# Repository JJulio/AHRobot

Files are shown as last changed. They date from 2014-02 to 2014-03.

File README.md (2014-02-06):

Air Hockey Robot (AHRobot)
==========================

Detailed build intructions (Robot and Air Hockey table) [English]: https://docs.google.com/document/d/1SXIIW5MG1uT7O6P6tBWwzjiLe_gj4_Z2HHhHXPehwso/edit?usp=sharing

Intrucciones de montaje de la mesa y el robot[Español]: https://docs.google.com/document/d/1hYupLZCxkPqST7Fa1OjUVXbfluQ60mGxMKnmPQMFq5Q/edit?usp=sharing

Video:  https://www.youtube.com/watch?v=CjzSeOg8oTs

Air Hockey Robot build using standard 3D printer parts: electronics, motors, rods, belts,...

Project description (English): http://cienciaycacharreo.blogspot.com.es/2014/02/new-project-air-hockey-robot-3d-printer.html

Blog del proyecto (Spanish):  http://cienciaycacharreo.blogspot.com.es/2014/02/nuevo-proyecto-air-hockey-robot-3d.html

Jose Julio 2014

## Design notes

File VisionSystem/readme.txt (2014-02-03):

AHRobot vision system:

This vision system is designed for PS3 Eye camera and use OpenCV libraries

If you want to compile from sources you need to install and configure OpenCV libraries

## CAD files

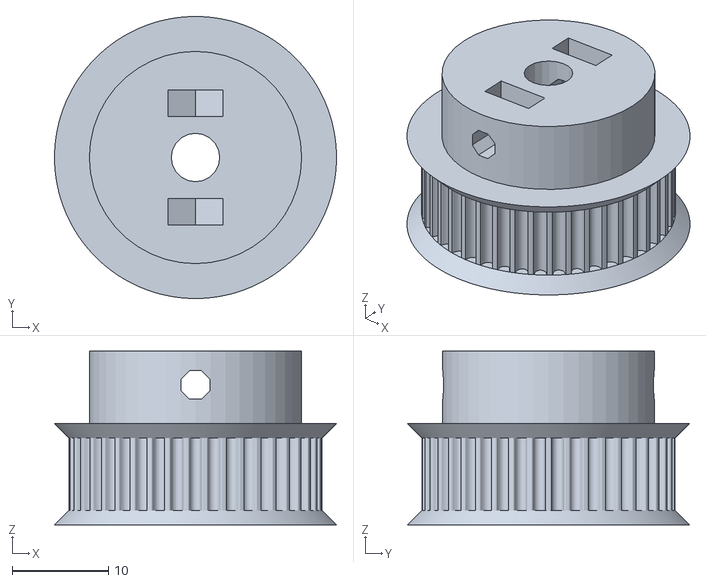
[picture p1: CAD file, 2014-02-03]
3DPrintable_parts/STL/AHR_Pulley_1.stl
29.2 x 29.2 x 18.0

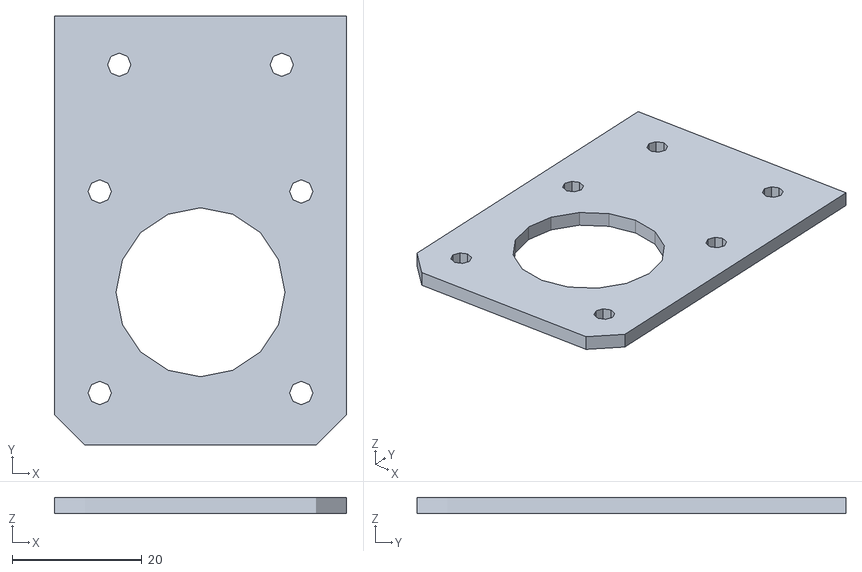
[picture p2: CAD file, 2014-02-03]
3DPrintable_parts/STL/AHR_x_motor_mount.stl
45.0 x 66.0 x 2.50

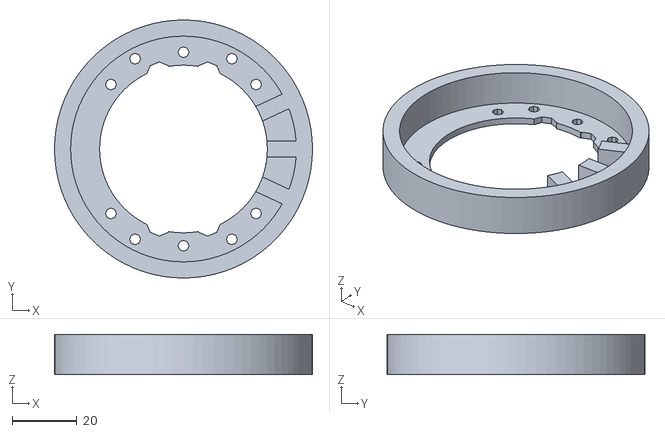
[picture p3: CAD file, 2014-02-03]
3DPrintable_parts/STL/AHR_x_carriage_pusher.stl
80.0 x 80.0 x 12.5

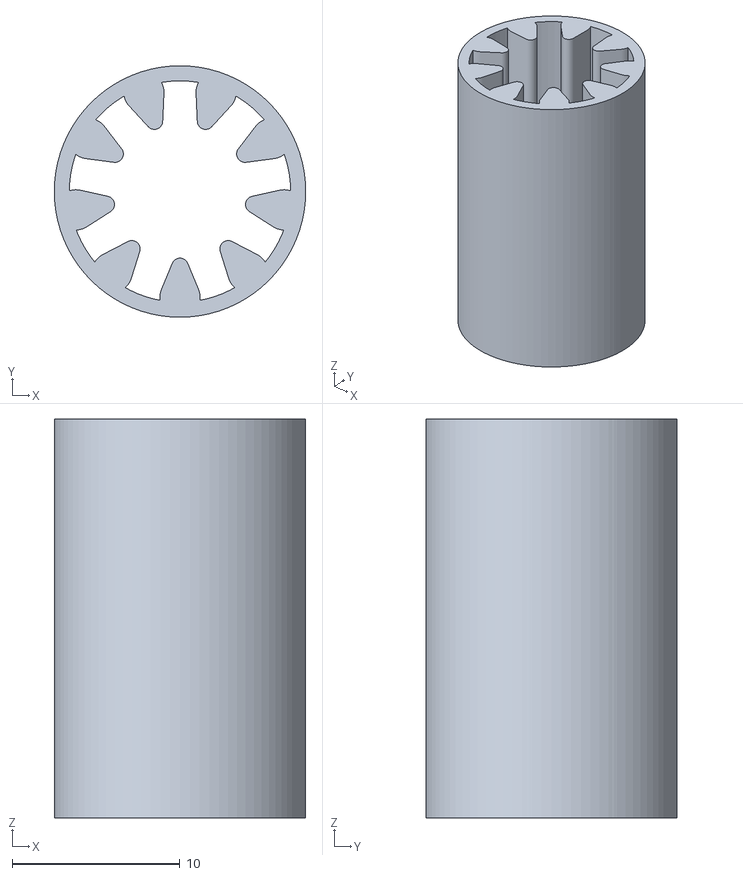
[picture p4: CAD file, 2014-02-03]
3DPrintable_parts/STL/PrintableBearing.stl
15.0 x 15.0 x 23.8

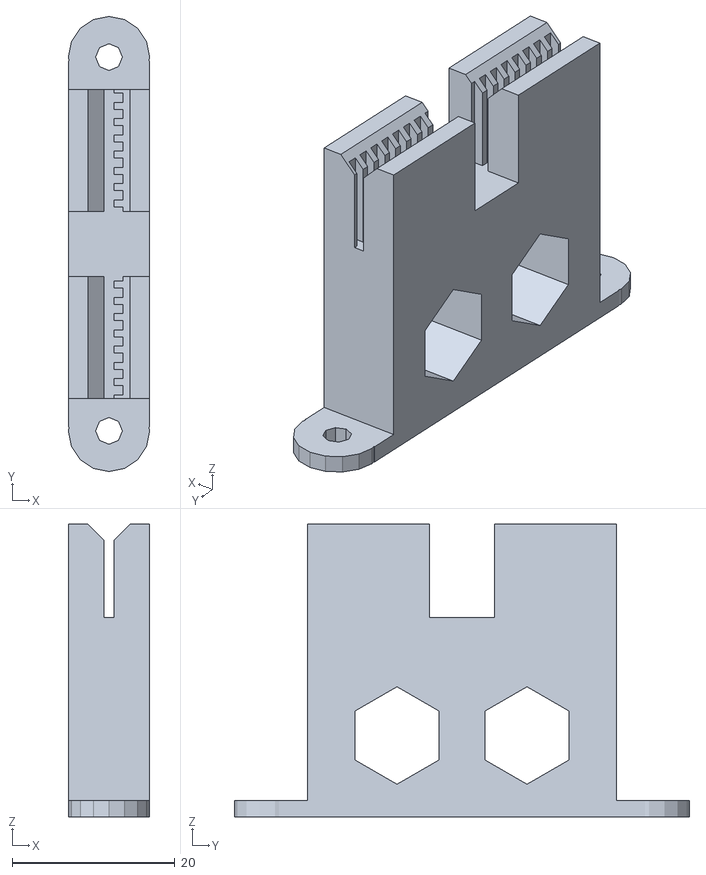
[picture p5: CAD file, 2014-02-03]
3DPrintable_parts/STL/AHR_x_carriage_belt.stl
10.0 x 56.0 x 36.0

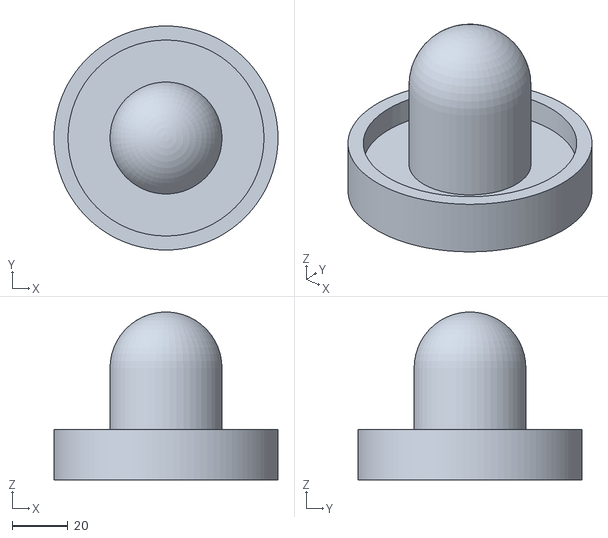
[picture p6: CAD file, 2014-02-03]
3DPrintable_parts/STL/pusher.stl
80.0 x 80.0 x 60.0

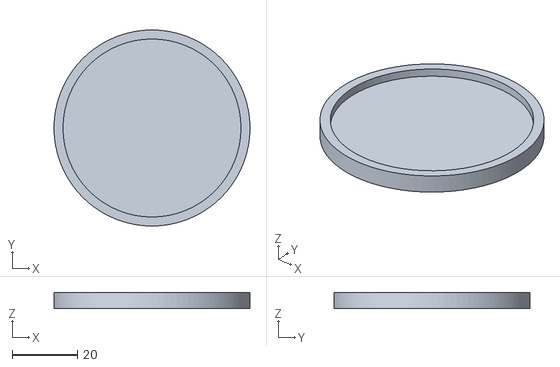
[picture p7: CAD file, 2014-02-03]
3DPrintable_parts/STL/puck_v2.stl
60.0 x 60.0 x 5.00

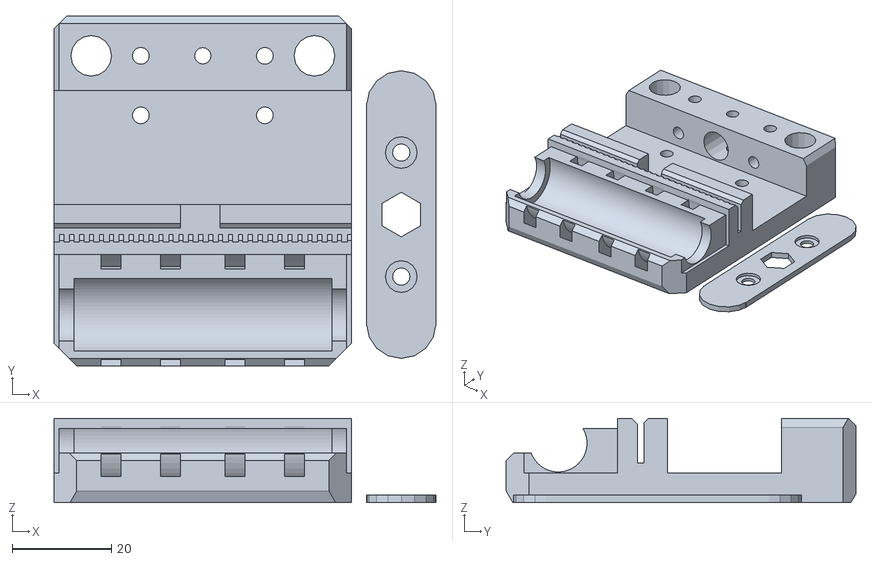
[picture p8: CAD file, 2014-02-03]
3DPrintable_parts/STL/AHR_y_carriage.stl
77.0 x 70.5 x 17.0

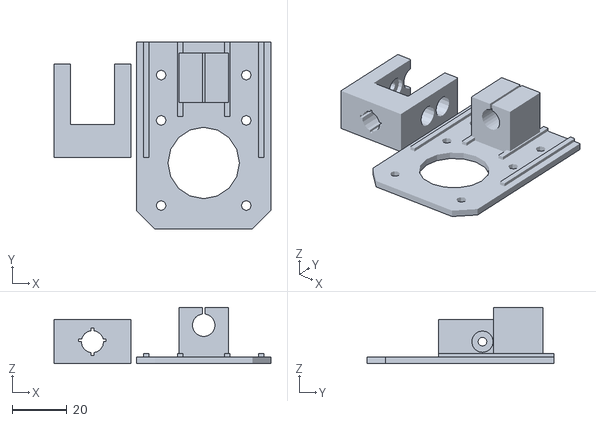
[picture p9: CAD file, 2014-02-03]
3DPrintable_parts/STL/AHR_y_axis_v2.stl
79.0 x 68.0 x 20.5

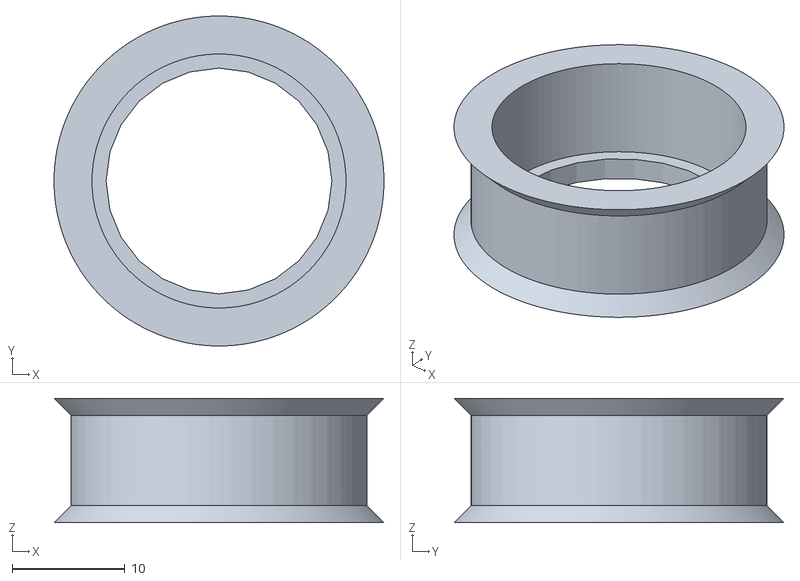
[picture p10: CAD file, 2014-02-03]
3DPrintable_parts/STL/AHR_Pulley_2.stl
29.2 x 29.2 x 11.0

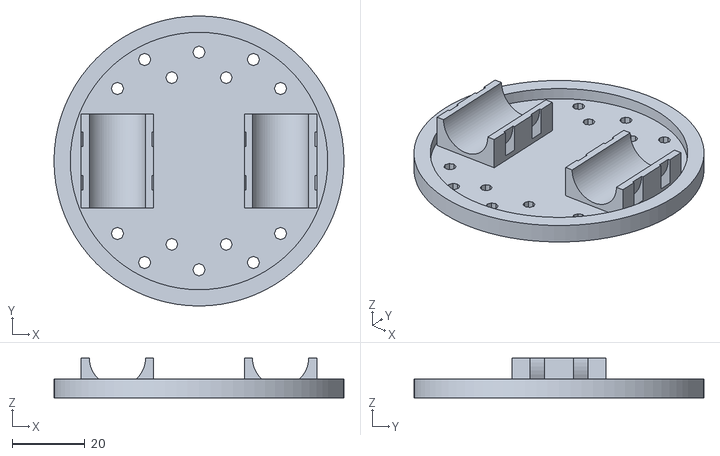
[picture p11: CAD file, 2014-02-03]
3DPrintable_parts/STL/AHR_x_carriage.stl
80.0 x 80.0 x 11.0

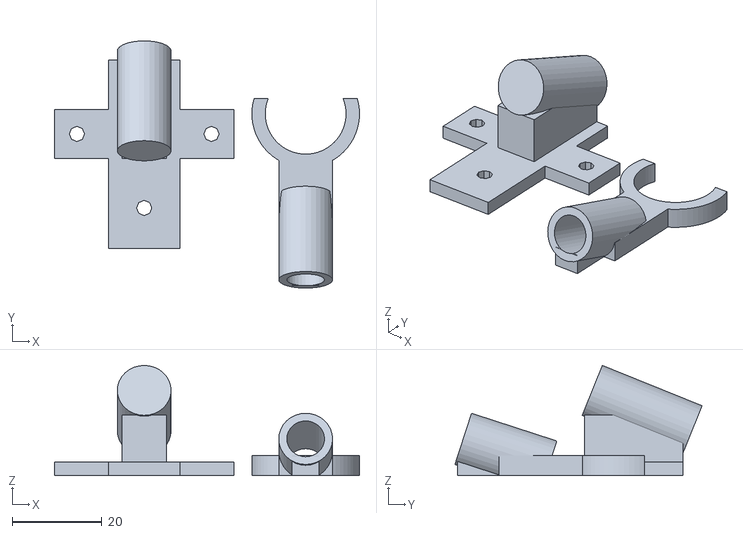
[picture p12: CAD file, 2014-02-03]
3DPrintable_parts/STL/AHR_PS3Camera_holder.stl
68.0 x 55.1 x 24.6

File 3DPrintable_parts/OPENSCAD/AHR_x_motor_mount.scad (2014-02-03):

// AIR HOCKEY ROBOT PROJECT (AHROBOT)
// 
// by Jose Julio

// X axis motor mount


motor_center_x = 22.5;
motor_center_y = -22.5;
base_height = 2.5;


module x_motor_mount_base()
{	
	translate([0,-46,0]) cube([45,46,base_height]); // Motor mount
	
	// mount part
	translate([0,0,0]) cube([motor_center_x*2,20,base_height]);

	// Reinforce
	//translate([2.5,-20,0]) cube([2,42,base_height*1.5]);
	//translate([16,-6,0]) cube([2,28,base_height*1.5]);
	//translate([32,-6,0]) cube([2,28,base_height*1.5]);
	//translate([45.5,-20,0]) cube([2,42,base_height*1.5]);

}

module x_motor_mount_holes()
{
	// Center motor hole
	translate([motor_center_x,motor_center_y,2]) cylinder(r=13,h=5,center=true,$fn=16);
	// Motor holes
	translate([motor_center_x-15.5,motor_center_y-15.5,2]) cylinder(r=1.8,h=5,center=true,$fn=8);
	translate([motor_center_x+15.5,motor_center_y-15.5,2]) cylinder(r=1.8,h=5,center=true,$fn=8);
	translate([motor_center_x-15.5,motor_center_y+15.5,2]) cylinder(r=1.8,h=5,center=true,$fn=8);
	translate([motor_center_x+15.5,motor_center_y+15.5,2]) cylinder(r=1.8,h=5,center=true,$fn=8);
 
	
   // Mount holes
	translate([motor_center_x-12.5,12.5,2]) cylinder(r=1.8,h=5,center=true,$fn=8);
	translate([motor_center_x+12.5,12.5,2]) cylinder(r=1.8,h=5,center=true,$fn=8);

	// motor mount cuts
	translate([motor_center_x*2+25,-motor_center_x*4+3,-1]) rotate([0,0,45]) cube([50,50,4]); // Motor mount
	translate([-25,-motor_center_x*4+3,-1]) rotate([0,0,45]) cube([50,50,4]); // Motor mount

}





translate([0,0,0]) rotate ([0,0,0]) difference()
{
x_motor_mount_base();
x_motor_mount_holes();
}

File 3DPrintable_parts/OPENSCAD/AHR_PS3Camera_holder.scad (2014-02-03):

// AIR HOCKEY ROBOT PROJECT (AHROBOT)
// 
// by Jose Julio

// PS3 Camera holder (needs a 8mm carbon tube)

module rod_base(angle=20,height=20)
{
	rotate([angle,0,0]) cylinder(r=6,h=height,$fn=32);
}

module rod_holes(angle=20,height=22)
{
	rotate([angle,0,0]) cylinder(r=4.2,h=height,$fn=32);
}

module PS3Cam_base()
{
	cylinder(r=12,h=4.5,$fn=64);
	translate([-6,-29,0]) cube([12,20,4.5]);
	// Support to print the rod holder
	translate([-3,-38.3,0]) cube([6,30,4.5]);
	// Rod holder
	translate([0,-18,2]) rod_base(72);
}

module PS3Cam_holes()
{
	translate([-15,3.4,-1]) cube([30,20,10]);
	translate([0,0,-1]) cylinder(r=9,h=6,$fn=64);
	// Rod holder
	translate([0,-18,2]) rod_holes(72);
	// Cut elements lower than 0
	translate([0,0,-5]) cube([200,200,10],center=true);
}

module base()
{
	translate([-20,0,0]) cube([40,11,3]);
	translate([-8,-20,0]) cube([16,42,3]);
	//translate([-8,-33,0]) cube([16,49,3]);
	//translate([-20,-11-22,0]) cube([40,11,3]);
	// Rod reinforcement
	translate([-5,0,2.5]) cube([10,22,11]);
	
	// Rod holder
	translate([0,24,10]) rod_base(68,24);
}

module holes()
{
	translate([-15,5.5,0]) cylinder(r=1.7,h=10,$fn=8,center=true);
	translate([15,5.5,0]) cylinder(r=1.7,h=10,$fn=8,center=true);
	translate([0,-11,0]) cylinder(r=1.7,h=10,$fn=8,center=true);

	//translate([-15,-27.5,0]) cylinder(r=1.7,h=10,$fn=8,center=true);
	//translate([15,-27.5,0]) cylinder(r=1.7,h=10,$fn=8,center=true);
	
// rod holder
	translate([0,24,10]) rod_holes(68,22);

	// Cut elements lower than 0
	translate([0,0,-5]) cube([200,200,10],center=true);
}


difference()
{
 base();
 holes();
}


translate([36,10,0]) difference()
{
 PS3Cam_base();
 PS3Cam_holes();
}

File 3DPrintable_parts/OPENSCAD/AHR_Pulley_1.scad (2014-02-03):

// AIR HOCKEY ROBOT PROJECT (AHROBOT)
// 
// 42 teeth GT2 pulley based on:

// Parametric Pulley with multiple belt profiles
// by droftarts January 2012

// Based on pulleys by:
// http://www.thingiverse.com/thing:11256 by me!
// https://github.com/prusajr/PrusaMendel by Josef Prusa
// http://www.thingiverse.com/thing:3104 by GilesBathgate
// http://www.thingiverse.com/thing:2079 by nophead

// dxf tooth data from http://oem.cadregister.com/asp/PPOW_Entry.asp?company=915217&elementID=07807803/METRIC/URETH/WV0025/F
// pulley diameter checked and modelled from data at http://www.sdp-si.com/D265/HTML/D265T016.html

/**
 * @name Pulley
 * @category Printed
 * @using 1 x m3 nut, normal or nyloc
 * @using 1 x m3x10 set screw or 1 x m3x8 grub screw
 */

// tuneable constants

teeth = 42;			// Number of teeth
profile = 12;		// GT2_2mm 1=MXL 2=40DP 3=XL 4=H 5=T2.5 6=T5 7=T10 8=AT5 9=HTD_3mm 10=HTD_5mm 11=HTD_8mm 12=GT2_2mm 13=GT2_3mm 14=GT2_5mm

motor_shaft = 5.03;	// NEMA17 motor shaft exact diameter = 5
m3_dia = 3.2;		// 3mm hole diameter
m3_nut_hex = 1;		// 1 for hex, 0 for square nut
m3_nut_flats = 5.74;	// normal M3 hex nut exact width = 5.5
m3_nut_depth = 2.74;	// normal M3 hex nut exact depth = 2.4, nyloc = 4

retainer = 1;		// Belt retainer above teeth, 0 = No, 1 = Yes
retainer_ht = 1.5;	// height of retainer flange over pulley, standard = 1.5
idler = 1;			// Belt retainer below teeth, 0 = No, 1 = Yes
idler_ht = 1.5;		// height of idler flange over pulley, standard = 1.5

pulley_t_ht = 7.5;	// length of toothed part of pulley, standard = 12
pulley_b_ht = 9;		// pulley base height, standard = 8. Set to same as idler_ht if you want an idler but no pulley.
pulley_b_dia = 22;	// pulley base diameter, standard = 20
no_of_nuts = 2;		// number of captive nuts required, standard = 1
nut_angle = 180;		// angle between nuts, standard = 90
nut_shaft_distance = 1.75;	// distance between inner face of nut and shaft, can be negative.


//	********************************
//	** Scaling tooth for good fit **
//	********************************
/*	To improve fit of belt to pulley, set the following constant. Decrease or increase by 0.1mm at a time. We are modelling the *BELT* tooth here, not the tooth on the pulley. Increasing the number will *decrease* the pulley tooth size. Increasing the tooth width will also scale proportionately the tooth depth, to maintain the shape of the tooth, and increase how far into the pulley the tooth is indented. Can be negative */

additional_tooth_width = 0.1; //mm

//	If you need more tooth depth than this provides, adjust the following constant. However, this will cause the shape of the tooth to change.

additional_tooth_depth = 0.2; //mm

// calculated constants

nut_elevation = pulley_b_ht/2-1;
m3_nut_points = 2*((m3_nut_flats/2)/cos(30)); // This is needed for the nut trap

// The following set the pulley diameter for a given number of teeth

MXL_pulley_dia = tooth_spacing (2.032,0.254);
40DP_pulley_dia = tooth_spacing (2.07264,0.1778);
XL_pulley_dia = tooth_spacing (5.08,0.254);
H_pulley_dia = tooth_spacing (9.525,0.381);
T2_5_pulley_dia = tooth_spaceing_curvefit (0.7467,0.796,1.026);
T5_pulley_dia = tooth_spaceing_curvefit (0.6523,1.591,1.064);
T10_pulley_dia = tooth_spacing (10,0.93);
AT5_pulley_dia = tooth_spaceing_curvefit (0.6523,1.591,1.064);
HTD_3mm_pulley_dia = tooth_spacing (3,0.381);
HTD_5mm_pulley_dia = tooth_spacing (5,0.5715);
HTD_8mm_pulley_dia = tooth_spacing (8,0.6858);
GT2_2mm_pulley_dia = tooth_spacing (2,0.254);
GT2_3mm_pulley_dia = tooth_spacing (3,0.381);
GT2_5mm_pulley_dia = tooth_spacing (5,0.5715);

// The following calls the pulley creation part, and passes the pulley diameter and tooth width to that module

if ( profile == 1 ) { pulley ( "MXL" , MXL_pulley_dia , 0.508 , 1.321 ); }
if ( profile == 2 ) { pulley ( "40 D.P." , 40DP_pulley_dia , 0.457 , 1.226 ); }
if ( profile == 3 ) { pulley ( "XL" , XL_pulley_dia , 1.27, 3.051 ); }
if ( profile == 4 ) { pulley ( "H" , H_pulley_dia ,1.905 , 5.359 ); }
if ( profile == 5 ) { pulley ( "T2.5" , T2_5_pulley_dia , 0.7 , 1.678 ); }
if ( profile == 6 ) { pulley ( "T5" , T5_pulley_dia , 1.19 , 3.264 ); }
if ( profile == 7 ) { pulley ( "T10" , T10_pulley_dia , 2.5 , 6.13 ); }
if ( profile == 8 ) { pulley ( "AT5" , AT5_pulley_dia , 1.19 , 4.268 ); }
if ( profile == 9 ) { pulley ( "HTD 3mm" , HTD_3mm_pulley_dia , 1.289 , 2.27 ); }
if ( profile == 10 ) { pulley ( "HTD 5mm" , HTD_5mm_pulley_dia , 2.199 , 3.781 ); }
if ( profile == 11 ) { pulley ( "HTD 8mm" , HTD_8mm_pulley_dia , 3.607 , 6.603 ); }
if ( profile == 12 ) { pulley ( "GT2 2mm" , GT2_2mm_pulley_dia , 0.764 , 1.494 ); }
if ( profile == 13 ) { pulley ( "GT2 3mm" , GT2_3mm_pulley_dia , 1.169 , 2.31 ); }
if ( profile == 14 ) { pulley ( "GT2 5mm" , GT2_5mm_pulley_dia , 1.969 , 3.952 ); }

// Functions

function tooth_spaceing_curvefit (b,c,d)
	= ((c * pow(teeth,d)) / (b + pow(teeth,d))) * teeth ;

function tooth_spacing(tooth_pitch,pitch_line_offset)
	= (2*((teeth*tooth_pitch)/(3.14159265*2)-pitch_line_offset)) ;

// Main Module

module pulley( belt_type , pulley_OD , tooth_depth , tooth_width )
	{
	echo (str("Belt type = ",belt_type,"; Number of teeth = ",teeth,"; Pulley Outside Diameter = ",pulley_OD,"mm "));
	tooth_distance_from_centre = sqrt( pow(pulley_OD/2,2) - pow((tooth_width+additional_tooth_width)/2,2));
	tooth_width_scale = (tooth_width + additional_tooth_width ) / tooth_width;
	tooth_depth_scale = ((tooth_depth + additional_tooth_depth ) / tooth_depth) ;


//	************************************************************************
//	*** uncomment the following line if pulley is wider than puller base ***
//	************************************************************************

	translate ([0,0, pulley_b_ht + pulley_t_ht + retainer_ht ]) rotate ([0,180,0])

	difference()
	 {	 
		union()
		{
			//base
	
			if ( pulley_b_ht < 2 ) { echo ("CAN'T DRAW PULLEY BASE, HEIGHT LESS THAN 2!!!"); } else {
				rotate_extrude($fn=pulley_b_dia*2)
				{
						square([pulley_b_dia/2-1,pulley_b_ht]);
						square([pulley_b_dia/2,pulley_b_ht-1]);
						translate([pulley_b_dia/2-1,pulley_b_ht-1]) circle(1);
				}
			}
	
		difference()
			{
			//shaft - diameter is outside diameter of pulley
			
			translate([0,0,pulley_b_ht]) 
			rotate ([0,0,360/(teeth*4)]) 
			cylinder(r=pulley_OD/2,h=pulley_t_ht, $fn=teeth*4);
	
			//teeth - cut out of shaft
		
			for(i=[1:teeth]) 
			rotate([0,0,i*(360/teeth)])
			translate([0,-tooth_distance_from_centre,pulley_b_ht -1]) 
			scale ([ tooth_width_scale , tooth_depth_scale , 1 ]) 
			{
			if ( profile == 1 ) { MXL();}
			if ( profile == 2 ) { 40DP();}
			if ( profile == 3 ) { XL();}
			if ( profile == 4 ) { H();}
			if ( profile == 5 ) { T2_5();}
			if ( profile == 6 ) { T5();}
			if ( profile == 7 ) { T10();}
			if ( profile == 8 ) { AT5();}
			if ( profile == 9 ) { HTD_3mm();}
			if ( profile == 10 ) { HTD_5mm();}
			if ( profile == 11 ) { HTD_8mm();}
			if ( profile == 12 ) { GT2_2mm();}
			if ( profile == 13 ) { GT2_3mm();}
			if ( profile == 14 ) { GT2_5mm();}
			}

			}
			
		//belt retainer / idler
		if ( retainer > 0 ) {translate ([0,0, pulley_b_ht + pulley_t_ht ]) 
		rotate_extrude($fn=teeth*4)  
		polygon([[0,0],[pulley_OD/2,0],[pulley_OD/2 + retainer_ht , retainer_ht],[0 , retainer_ht],[0,0]]);}
		
		if ( idler > 0 ) {translate ([0,0, pulley_b_ht - idler_ht ]) 
		rotate_extrude($fn=teeth*4)  
		polygon([[0,0],[pulley_OD/2 + idler_ht,0],[pulley_OD/2 , idler_ht],[0 , idler_ht],[0,0]]);}
	
		}
	   
		//hole for motor shaft
		translate([0,0,-1])cylinder(r=motor_shaft/2,h=pulley_b_ht + pulley_t_ht + retainer_ht + 2,$fn=motor_shaft*4);
				
		//captive nut and grub screw holes
	
		if ( pulley_b_ht < m3_nut_flats ) { echo ("CAN'T DRAW CAPTIVE NUTS, HEIGHT LESS THAN NUT DIAMETER!!!"); } else {
		if ( (pulley_b_dia - motor_shaft)/2 < m3_nut_depth + 3 ) { echo ("CAN'T DRAW CAPTIVE NUTS, DIAMETER TOO SMALL FOR NUT DEPTH!!!"); } else {
	
			for(j=[1:no_of_nuts]) rotate([0,0,j*nut_angle])
			translate([0,0,nut_elevation])rotate([90,0,0])
	
			union()
			{
				//entrance
				translate([0,-pulley_b_ht/4-0.5,motor_shaft/2+m3_nut_depth/2+nut_shaft_distance]) cube([m3_nut_flats,pulley_b_ht/2+1,m3_nut_depth],center=true);
	
				//nut
				if ( m3_nut_hex > 0 )
					{
						// hex nut
						translate([0,0.25,motor_shaft/2+m3_nut_depth/2+nut_shaft_distance]) rotate([0,0,30]) cylinder(r=m3_nut_points/2,h=m3_nut_depth,center=true,$fn=6);
					} else {
						// square nut
						translate([0,0.25,motor_shaft/2+m3_nut_depth/2+nut_shaft_distance]) cube([m3_nut_flats,m3_nut_flats,m3_nut_depth],center=true);
					}
	
				//grub screw hole
				rotate([0,0,22.5])cylinder(r=m3_dia/2,h=pulley_b_dia/2+1,$fn=8);
			}
		}}
	 }
	   
	}


// Tooth profile modules
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

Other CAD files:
3DPrintable_parts/OPENSCAD/AHR_Pulley_2.scad
3DPrintable_parts/OPENSCAD/AHR_x_carriage.scad
3DPrintable_parts/OPENSCAD/AHR_x_carriage_belt.scad
3DPrintable_parts/OPENSCAD/AHR_x_carriage_pusher.scad
3DPrintable_parts/OPENSCAD/AHR_y_axis_v2.scad
3DPrintable_parts/OPENSCAD/AHR_y_carriage.scad
3DPrintable_parts/OPENSCAD/PrintableBearing.scad
3DPrintable_parts/OPENSCAD/puck_v2.scad
3DPrintable_parts/OPENSCAD/pusher.scad

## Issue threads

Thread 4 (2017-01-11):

Question

shinichikudou09, 2017-01-11:
Sir JJulio can i ask a question? about the main function. the argument

if (argc < 2)
	{
		printf("USAGE: AHR.exe COMPORT PUCK_HMIN PUCK_HMAX PUCK_SMIN PUCK_SMAX PUCK_VMIN PUCK_VMAX ROBOT_HMIN ROBOT_HMAX ROBOT_SMIN ROBOT_SMAX ROBOT_VMIN ROBOT_VMAX FPS\n");
		printf("Example with default paremeters: AHR.exe COM18\n");
		// H : 70-94 S: 60-150 V: 10-145   GREEN EVA FOAM (PUCK)
		// H : 5-20  S: 110-200 V: 90-200  ORANGE EVA FOAM (ROBOT)
		printf("Example full parameters: AHR.exe COM4 70 94 60 150 10 145 5 20 110 200 90 200 60\n");
		return -1;
	}

always get executed do you know why? is it about the wchar_t* things? i am using Microsoft Visual c++ 2010 Express.

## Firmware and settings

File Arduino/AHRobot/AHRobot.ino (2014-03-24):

// AHR: AIR HOCKEY ROBOT PROJECT
// Author: Jose Julio (@jjdrones)
// Hardware: Arduino MEGA + Ramps 1.4
// Date: 18/11/2013
// Last updated: 24/03/2014
// Version: 1.05
// Project page : 
//    Spanish: http://cienciaycacharreo.blogspot.com.es/2014/02/nuevo-proyecto-air-hockey-robot-3d.html 
//    English: http://cienciaycacharreo.blogspot.com.es/2014/02/new-project-air-hockey-robot-3d-printer.html
// GIT repository: https://github.com/JJulio/AHRobot
// License: Open Software GPL License

// ROBOT and USER configuration parameters
#include "Configuration.h"
#include "Definitions.h"   // Variable definitions

void setup() 
{ 
  // STEPPER MOTOR PINS (SAME AS RAMPS 1.4)
  // X MOTOR
  //     X-STEP: A0    (PF0)
  //     X-DIR:  A1    (PF1)
  //     X-ENABLE: D38 (PD7)
  // Y MOTOR (Y-LEFT)
  //     Y-STEP: A6    (PF6)
  //     Y-DIR:  A7    (PF7)
  //     Y-ENABLE: A2  (PF2)
  // Z MOTOR (Y-RIGHT)
  //     Z-STEP: D46   (PL3)
  //     Z-DIR:  D48   (PL1)
  //     Z-ENABLE: A8  (PK0)

  // STEPPER PINS 
  // X_AXIS
  pinMode(38,OUTPUT);  // ENABLE MOTOR
  pinMode(A0,OUTPUT);  // STEP MOTOR
  pinMode(A1,OUTPUT);  // DIR MOTOR
  // Y_AXIS (Y-LEFT)
  pinMode(A2,OUTPUT);  // ENABLE MOTOR
  pinMode(A6,OUTPUT);  // STEP MOTOR
  pinMode(A7,OUTPUT);  // DIR MOTOR
  // Z_AXIS (Y-RIGHT)
  pinMode(A8,OUTPUT);  // ENABLE MOTOR
  pinMode(46,OUTPUT);  // STEP MOTOR
  pinMode(48,OUTPUT);  // DIR MOTOR 

  pinMode(A3,OUTPUT);  // DEBUG PIN FOR OSCILLOSCOPE TIME MEASURES

  pinMode(19,INPUT);  // RX1 Serial Port 1
  pinMode(18,OUTPUT); // TX1

  //FANS and LEDS
  pinMode(8,OUTPUT);
  pinMode(9,OUTPUT);
  pinMode(10,OUTPUT);
  pinMode(13,OUTPUT);

  // Disable Motors
  digitalWrite(38,HIGH);
  digitalWrite(A2,HIGH);
  digitalWrite(A8,HIGH);

  Serial.begin(115200);
  Serial.println("AHR Robot version 1.05");
  delay(500);
  Serial.println("Initializing robot...");
  delay(2000);

  cameraProcessInit();  // Camera variable initializations
  
  // Robot positions initialization
  defense_position = ROBOT_DEFENSE_POSITION;   // Robot y axis defense position
  attack_position = ROBOT_DEFENSE_ATTACK_POSITION;   // Robot y axis position for defense+attack

  //LED blink
  for (uint8_t k=0;k<4;k++)
  {
    digitalWrite(13,HIGH);
    delay(300);
    digitalWrite(13,LOW);
    delay(300);
  } 

  // We use TIMER 1 for stepper motor X AXIS and Timer 3 for Y AXIS
  // STEPPER MOTORS INITIALIZATION
  // TIMER1 CTC MODE
  TCCR1B &= ~(1<<WGM13);
  TCCR1B |=  (1<<WGM12);
  TCCR1A &= ~(1<<WGM11); 
  TCCR1A &= ~(1<<WGM10);

  // output mode = 00 (disconnected)
  TCCR1A &= ~(3<<COM1A0); 
  TCCR1A &= ~(3<<COM1B0); 

  // Set the timer pre-scaler
  // Generally we use a divider of 8, resulting in a 2MHz timer on 16MHz CPU
  TCCR1B = (TCCR1B & ~(0x07<<CS10)) | (2<<CS10);

  OCR1A = ZERO_SPEED;   // Motor stopped
  dir_x = 0;
  TCNT1 = 0;

  // We use TIMER 3 for stepper motor Y AXIS 
  // STEPPER MOTORS INITIALIZATION
  // TIMER3 CTC MODE
  TCCR3B &= ~(1<<WGM13);
  TCCR3B |=  (1<<WGM12);
  TCCR3A &= ~(1<<WGM11); 
  TCCR3A &= ~(1<<WGM10);

  // output mode = 00 (disconnected)
  TCCR3A &= ~(3<<COM1A0); 
  TCCR3A &= ~(3<<COM1B0); 

  // Set the timer pre-scaler
  // Generally we use a divider of 8, resulting in a 2MHz timer on 16MHz CPU
  TCCR3B = (TCCR3B & ~(0x07<<CS10)) | (2<<CS10);

  OCR3A = ZERO_SPEED;   // Motor stopped
  dir_y = 0;
  TCNT3 = 0;

  //Initializing init position
  position_x = ROBOT_INITIAL_POSITION_X*X_AXIS_STEPS_PER_UNIT;
  position_y = ROBOT_INITIAL_POSITION_Y*Y_AXIS_STEPS_PER_UNIT;

  delay(4000);

  Serial.println("Initializing Stepper motors...");
  delay(1000);
  TIMSK1 |= (1<<OCIE1A);  // Enable Timer1 interrupt
  TIMSK3 |= (1<<OCIE1A);  // Enable Timer1 interrupt

  // Enable steppers
  digitalWrite(38,LOW);   // X-axis
  digitalWrite(A2,LOW);   // Y-axis left
  digitalWrite(A8,LOW);   // Z-axis (Y-axis right)

  // Output parameters
  Serial.print("Max_acceleration_x: ");
  Serial.println(max_acceleration_x);
  Serial.print("Max_acceleration_y: ");
  Serial.println(max_acceleration_y);
  Serial.print("Max speed X: ");
  Serial.println(MAX_SPEED_X);
  Serial.print("Max speed Y: ");
  Serial.println(MAX_SPEED_Y);
  Serial.println("Moving to initial position...");
  Serial.println("Ready!!");
  delay(1000);

  // Initializing Robot command variables
  com_pos_x = ROBOT_CENTER_X;
  com_pos_y = defense_position;
  com_speed_x = MAX_SPEED_X;
  com_speed_y = MAX_SPEED_Y;

  setSpeedS(com_speed_x,com_speed_y);
  setPosition(com_pos_x,com_pos_y);

  timer_old = micros();
  timer_packet_old = timer_old;
  micros_old = timer_old;


  // Enable Air Hockey FANS
  //digitalWrite(9,HIGH);
  //digitalWrite(10,HIGH);
  analogWrite(9,FAN1_SPEED);
  analogWrite(10,FAN2_SPEED);
}

// Main loop
void loop() 
{ 
  int dt;
  uint8_t logOutput=0;

  debug_counter++;
  timer_value = micros();
  if ((timer_value-timer_old)>=1000)  // 1Khz loop
  {
    //dt = (timer_value-timer_old)/1000;
    timer_old = timer_value;

    loop_counter++;

    packetRead();
    if (newPacket)
    {
      //dt = (timer_value-timer_packet_old)/1000.0;
      dt = 16;  //60 Hz = 16.66ms
      timer_packet_old = timer_value;
      newPacket=0;
      logOutput = 1;
      //Serial.print("P");

      // Puck detection and trayectory prediction
      cameraProcess(puckPixX,puckPixY,dt);

      // Robot position detection for missing steps detection in steppers.
      robotDetection(robotPixX,robotPixY);
      missingStepsDetection();

      // Robot strategy based on puck prediction
      newDataStrategy();
      
     
    }  // End packet received
    
    
    
    // Strategy : Robot behaviour
    robotStrategy();
    
    // Console output
    if (logOutput)
      {
      logOutput = 0;
      Serial.print(robot_status);
      Serial.print(" ");
      Serial.print(com_pos_x);
      Serial.print(" ");
      Serial.print(com_pos_y);
      Serial.print(" ");
      Serial.println(speed_y);
      }
    // DEBUG : PUCK POSITION
    if (loop_counter == 4000)
      {
        Serial.print("PUCK POSITION: ");
        Serial.print(puckCoordX);
        Serial.print(",");
        Serial.println(puckCoordY);
      }
      
    // DEBUG: We inform of the position error of the robot as seen in the camera (util for calibrations)
    if (loop_counter == 4002)
      {
        Serial.print("ROBOT ERROR: ");
        Serial.print(robotMissingStepsErrorX);
        Serial.print(",");
        Serial.println(robotMissingStepsErrorY);
      }

    
    positionControl();
  } // 1Khz loop
}

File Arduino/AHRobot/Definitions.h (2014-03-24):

// AHR AIR HOCKEY ROBOT PROJECT

#include <stdint.h>

// Variable definitions

// Log and Timer variables
long loop_counter;
long timer_old;
long timer_packet_old;
long timer_value;
int debug_counter;

uint32_t micros_old;

// We have 2 axis => 2 motor controls 0=X axis   1=Y axis  (Y AXIS HAS 2 MOTORS Left and Right)
int16_t speed_m[2];           // Actual speed of motors
uint8_t dir_m[2];             // Actual direction of steppers motors

uint16_t counter_m[2];        // counters for periods
uint16_t period_m[2][8];      // Eight subperiods 
uint8_t period_m_index[2];    // index for subperiods

// kinematic variables
// position, speed and acceleration are in step units
volatile int16_t position_x;  // This variables are modified inside the Timer interrupts
volatile int16_t position_y;

int16_t speed_x;
int16_t speed_y;
int8_t dir_x;     //(dir=1 positive, dir=-1 negative)
int8_t dir_y;  
int16_t target_position_x;
int16_t target_position_y;
int16_t target_speed_x;
int16_t target_speed_y;
int16_t max_acceleration_x = MAX_ACCEL_X;  // default maximun acceleration
int16_t max_acceleration_y = MAX_ACCEL_Y;
int16_t acceleration_x = MAX_ACCEL_X;
int16_t acceleration_y = MAX_ACCEL_Y;
int16_t accel_ramp = ACCEL_RAMP_MIN;

int16_t pos_stop_x;
int16_t pos_stop_y;

// Trajectory prediction
// Puck variables
int puckPixX;
int puckPixY;
int puckSize;
int puckCoordX;
int puckCoordY;
int puckOldCoordX;
int puckOldCoordY;
int puckSpeedX;
int puckSpeedY;
int puckOldSpeedX;
int puckOldSpeedY;
int puckSpeedXAverage;
int puckSpeedYAverage;


// Robot variables
uint8_t robot_status;   // Robot modes: 0 Init 1 Defense 2 Defense+Atack 3 Atack
int robotPixX;
int robotPixY;
int robotCoordX;
int robotCoordY;
int robotCoordSamples=0;
int robotCoordXAverage=0;
int robotCoordYAverage=0;
int robotMissingStepsErrorX;
int robotMissingStepsErrorY;
int defense_position;
int attack_position;
long attack_time;
int attack_pos_x;
int attack_pos_y;
int attack_predict_x;
int attack_predict_y;
uint8_t attack_status;
int8_t predict_status;  // 1 Puck is going to goal
int8_t predict_bounce;  // 1 if puck came from a bounce
int8_t predict_bounce_status;
int predict_x;    // X position at impact (mm)
int predict_y;
int predict_x_old;
int predict_y_old;
int predict_time;   // time to impact in ms
int predict_x_attack;
int predict_time_attack;
char tempStr2[80];  // for debug porpouses

// Camera variables
int cam_center_x;
int cam_center_y;
uint16_t cam_timestamp;
float cam_pix_to_mm;
float cam_rotation;  //Camera rotation in radians 


// Serial port  variables
char SBuffer[14];
uint8_t readStatus;
uint8_t readCounter;
uint8_t newPacket;
uint16_t com_pos_x;
uint16_t com_pos_y;
uint16_t com_speed_x;
uint16_t com_speed_y;
uint16_t target_x_mm;
uint16_t target_y_mm;
int16_t user_speed_x;
int16_t user_speed_y;
int16_t filt_user_speed_x;
int16_t filt_user_speed_y;


// Some util functions...
int freeRam () {
  extern int __heap_start, *__brkval; 
  int v; 
  return (int) &v - (__brkval == 0 ? (int) &__heap_start : (int) __brkval); 
}

// Arduino abs function sometimes fail!
int16_t myAbs(int16_t param)
{
  if (param<0)
    return -param;
  else
    return param;
}

// Extract sign of a variable
int sign(int val)
{
  if (val<0)
    return(-1);
  else
    return(1);
}

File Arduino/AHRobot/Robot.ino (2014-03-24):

// AHR AIR HOCKEY ROBOT PROJECT

// Each time a new data packet from camera is reveived this function is called
void newDataStrategy()
{
  // predict_status == 1 => Puck is moving to our field directly
  // predict_status == 2 => Puck is moving to our field with a bounce
  // predict_status == 3 => Puck is in our field moving slowly, attack?
    
    // Default
    robot_status = 0;   // Going to initial position (defense)
    
    if ((predict_status==1)&&(predict_time<350))
      {
      // WE  come from a bounce?
      if (predict_bounce == 1)
        {
        if ((puckSpeedYAverage)>-150)
          // puck is moving slowly...
          robot_status = 2;  // Defense+Attack
        else
          {
          if (predict_x < 200)
            predict_x = 200;
          if (predict_x > 400)
            predict_x = 400;
          robot_status = 4;
          }
        }
      else
        {
        if ((predict_x > (ROBOT_MIN_X+35))&&(predict_x < (ROBOT_MAX_X-35))) 
          robot_status = 2; //2  //Defense+attack mode
        else
          robot_status = 1; //1
        }
      }
    
    // Prediction with side bound
    if ((predict_status==2)&&(predict_time<350))
      {
      robot_status = 1;  //1   // Defense mode
      // We limit the movement in this phase
      if (predict_x < 200)
        predict_x = 200;
      if (predict_x > 400)
        predict_x = 400;
      }
   
    // If the puck is moving slowly in the robot field we could start an attack
    if ((predict_status==0)&&(puckCoordY < ROBOT_CENTER_Y)&&(myAbs(puckSpeedY)<50))
      robot_status = 3; //3
      
}

void robotStrategy()
{
  switch(robot_status) {
      case 0:
        // Go to defense position
        com_pos_y = defense_position;
        com_pos_x = ROBOT_CENTER_X;  //center X axis
        setSpeedS(com_speed_x,com_speed_y);
        setPosition(com_pos_x,com_pos_y);
        attack_time = 0;
        break;
      case 1:
        // Defense mode (only move on X axis on the defense line)
        com_pos_y = defense_position;
        com_pos_x = predict_x;
        setSpeedS(com_speed_x,com_speed_y);
        setPosition(com_pos_x,com_pos_y);
        attack_time = 0;
        break;
      case 2:
        // Defense+attack
        if (predict_time_attack<180)  // If time is less than 180ms we start the attack
          {
          com_pos_y = attack_position + 80;
          com_pos_x = predict_x_attack;
          setSpeedS(com_speed_x,com_speed_y);
          setPosition(com_pos_x,com_pos_y); // We use a straight line path
          }
        else      // Defense position
          {
          com_pos_y = predict_y;
          com_pos_x = predict_x;  // predict_x_attack;
          setSpeedS(com_speed_x,com_speed_y);
          setPosition(com_pos_x,com_pos_y);
          attack_time = 0;
          }
        
        break;
      case 3:
        // ATTACK MODE
        if (attack_time == 0)
          {
          attack_predict_x = predictPuckXPosition(500);
          attack_predict_y = predictPuckYPosition(500);
          if ((attack_predict_x > 120)&&(attack_predict_x < 480)&&(attack_predict_y >180)&&(attack_predict_y<320))
            {
            attack_time = millis() + 500;  // Prepare an attack in 500ms
            attack_pos_x = attack_predict_x;  // predict_x
            attack_pos_y = attack_predict_y;  // predict_y
            Serial.print("AM:");
            //Serial.print(attack_time);
            //Serial.print(",");
            Serial.print(attack_pos_x);
            Serial.print(",");
            Serial.println(attack_pos_y);
            //Serial.print(" ");
            // Go to pre-attack position
            com_pos_x = attack_pos_x;
            com_pos_y = attack_pos_y-120;
            setSpeedS(com_speed_x/2,com_speed_y/2);
            setPosition(com_pos_x,com_pos_y);
            attack_status = 1;
            }
          else
            {
            attack_time = 0;  // Continue...
            attack_status = 0;
            // And go to defense position
            com_pos_y = defense_position;
            com_pos_x = ROBOT_CENTER_X;  //center X axis
            setSpeedS(com_speed_x/2,com_speed_y/2);
            setPosition(com_pos_x,com_pos_y);
            }
          }
        else
          {
          if (attack_status == 1)
            {
            if ((attack_time-millis())<200)
              {
              // Attack movement
              com_pos_x = predictPuckXPosition(200); 
              com_pos_y = predictPuckYPosition(200) + 80;
              setSpeedS(com_speed_x,com_speed_y);
              setPosition(com_pos_x,com_pos_y);
        
              Serial.print("ATTACK:");
              Serial.print(com_pos_x);
              Serial.print(",");
              Serial.println(com_pos_y-80);
                
              attack_status = 2; // Attacking      
              }
            else  // attack_status=1 but it´s no time to attack yet
              {
              // Go to pre-attack position
              com_pos_x = attack_pos_x;
              com_pos_y = attack_pos_y-120;
              setSpeedS(com_speed_x/2,com_speed_y/2);
              setPosition(com_pos_x,com_pos_y);
              }
            }
          if (attack_status==2)
            {
            if (millis()>(attack_time+80))  // Attack move is done? => Reset to defense position
              {
              Serial.print("RESET");
              attack_time = 0;
              robot_status = 0;
              attack_status = 0;
              }
            }
          }
        break;
      case 4:
        // The puck came from a bounce
        // Only defense now (we could improve this in future)
        // Defense mode (only move on X axis on the defense line)
        com_pos_y = defense_position;
        com_pos_x = predict_x;
        setSpeedS(com_speed_x,com_speed_y);
        setPosition(com_pos_x,com_pos_y);
        attack_time = 0;
        break;
      default:
        // Default : go to defense position
        com_pos_y = defense_position;
        com_pos_x = ROBOT_CENTER_X; // center
        setSpeedS(com_speed_x,com_speed_y);
        setPosition(com_pos_x,com_pos_y);
        attack_time = 0;
    }
}

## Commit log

2014-02-03 First commit of project
    Air hockey project:
    Arduino code
    3D parts
    OpenCV vision system
    [AHR_PS3Camera_holder.scad, AHR_PS3Camera_holder.stl, AHR_Pulley_1.scad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]
2014-03-24 AHR Motor test update
    Revised code
    [Configuration.h]
2014-03-24 Stepper driver update
    Now it´s compatible with DRV8825 drivers
2014-03-24 Strategy and Prediction updates
    Update prediction algorithm and strategy
    [Configuration.h]
2014-03-24 MOTOR X TEST Update
    [Configuration.h]
2014-03-24 MOTOR Y TEST
    [Configuration.h]
